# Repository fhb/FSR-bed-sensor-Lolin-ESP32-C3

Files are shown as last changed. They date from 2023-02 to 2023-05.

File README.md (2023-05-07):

# FSR-bed-sensor-Lolin-ESP32-C3
This project includes everything needed to build a bed occupancy sensor inspired by https://community.home-assistant.io/t/fsr-the-best-bed-occupancy-sensor/365795:
One PCB design for connecting two FSR sensors to an Lolin ESP32-C3 pico (pin compatible to Lolin ESP32-C3 mini) and a case for it. There are also two options to add a temperature sensor using the I2c port on the Lolin ESP32-C3. Everything has been tested and works. Make sure the JST-XH plugs are properly plugged in. 

List of materials:

* 2x JST_XH 2 pins male + female connector
* 1x Wemos Lolin ESP32-C3 pico
* 2x 8er Pinleiste
* 2x 8er Buchsenleiste
* 2x RM063 Potentiometer (V2)
* 2x FSR SF15-600 10kg


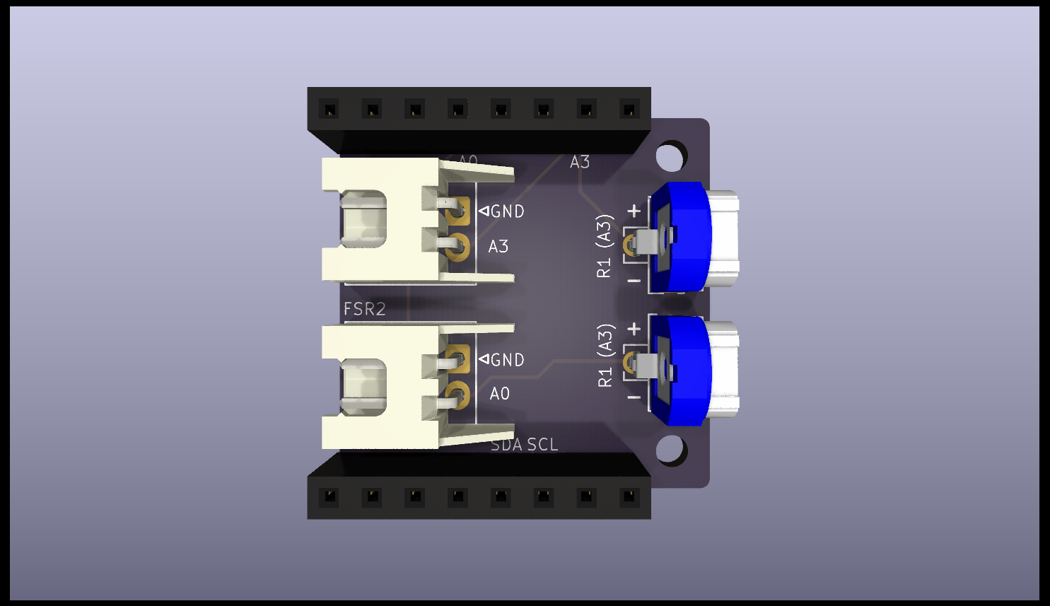
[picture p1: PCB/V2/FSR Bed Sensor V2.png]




Option 1:The Wemos SHT-30 is the easiest option as ready made SH1.0 4Pin cables are available, that's the option I ended up using and designing a case for.
* 1x Wemos SHT-30 (https://www.wemos.cc/en/latest/d1_mini_shield/sht30.html)
* I2C Cable 10cm für LOLIN (WEMOS) SH1.0 4Pins



Option 2: You could also make your own JST-XH to JST-SH1.0 cable and solder a JST-XH connector to a BME280 5V Board. 
* JST-SH1.0 male connector --- 4 wire ---  JST-XH female + male connector 
* BME280 5V Board (I2C)

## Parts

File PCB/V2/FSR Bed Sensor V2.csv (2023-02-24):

Id | Designator | Footprint | Quantity | Designation | Supplier and ref
1 | FSR2 | JST_XH_S2B-XH-A-1_1x02_P2.50mm_Horizontal | 1 | JST_XH_S2B-XH-A-1_1x02_P2.50mm_Horizontal
2 | R1 (A3),R1 (A3) | Potentiometer_Runtron_RM-063_Horizontal | 2 | Potentiometer_Runtron_RM-063_Horizontal
3 | FSR1 | JST_XH_S2B-XH-A-1_1x02_P2.50mm_Horizontal | 1 | ST_XH_S2B-XH-A-1_1x02_P2.50mm_Horizontal
4 | Wemos LOLIN C3 Pico | WEMOS_Lolin_ESP32-C3_Pico | 1 | ESP32-C3

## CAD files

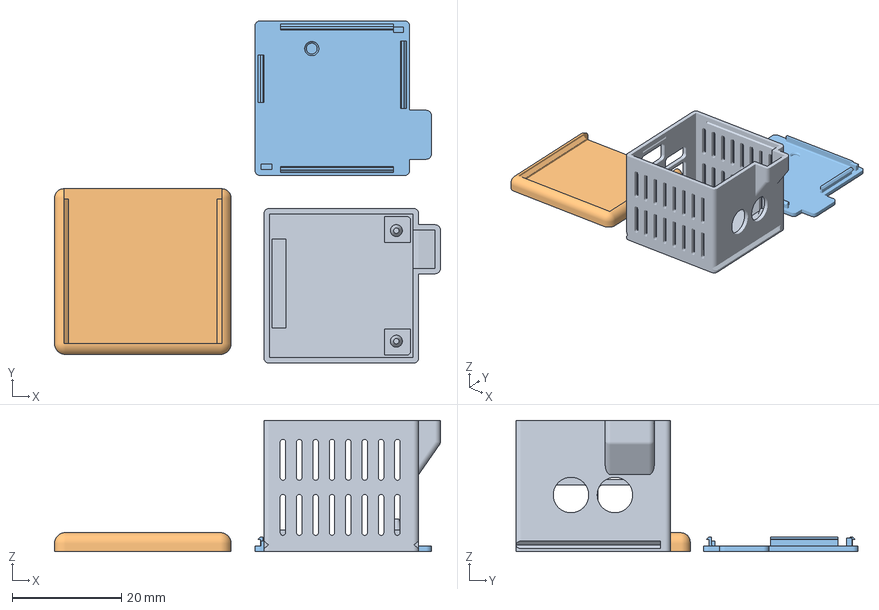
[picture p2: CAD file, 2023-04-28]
Case/FSR Bed Sensor.3mf
70.8 x 62.8 x 24.1 mm
FSR Bed Sensor_Body
FSR Bed Sensor_Mount
FSR Bed Sensor_Lid

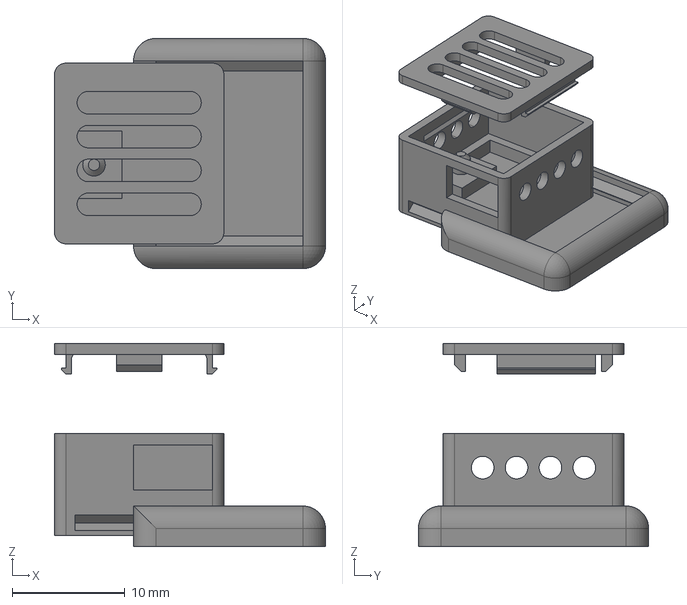
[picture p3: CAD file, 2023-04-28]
Case/Step files/Temp Sensor Case.step
24.0 x 20.4 x 18.0 mm
Lid
Folder 03

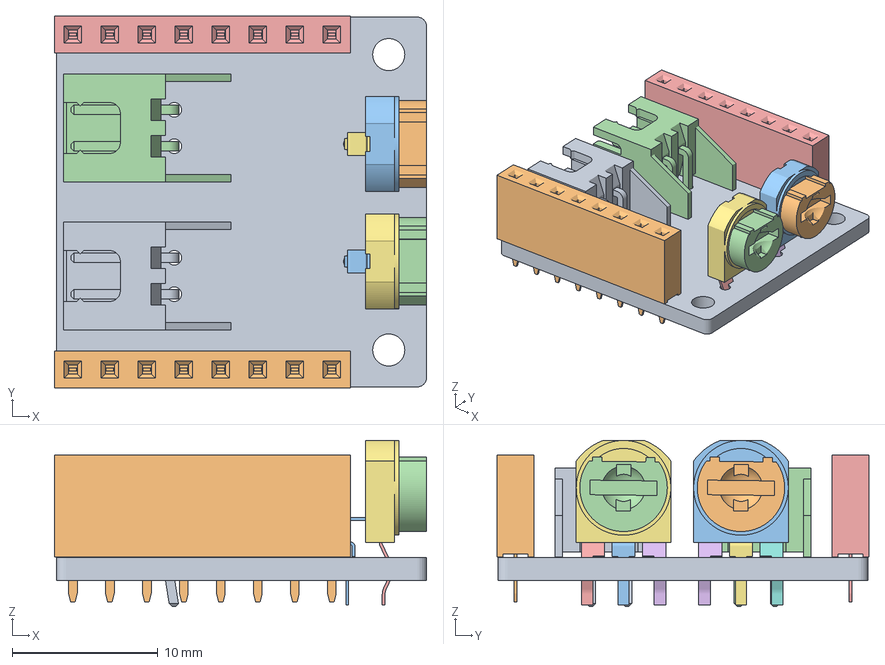
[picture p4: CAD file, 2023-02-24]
PCB/V2/case/FSR Bed Sensor Copy_FSR Bed Sensor V2.step.3mf
25.6 x 25.5 x 11.4 mm
Imported_01
Imported_02
Imported_10
Imported_14
Imported_03
Imported_08
Imported_06
Imported_07
Imported_04
Imported_09
Imported_11
Imported_05
Imported_13
Imported_12
Imported_15

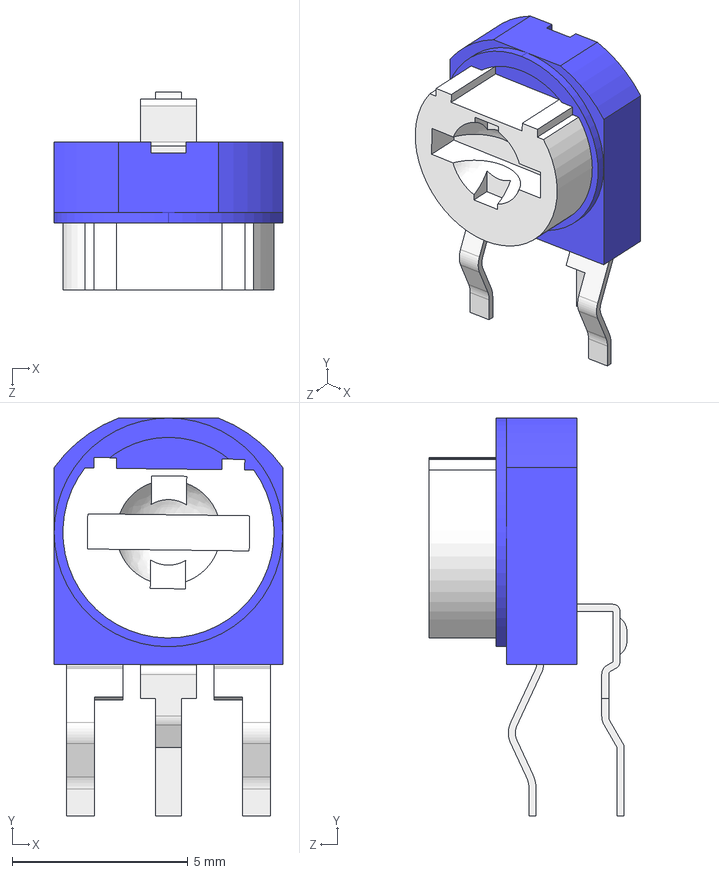
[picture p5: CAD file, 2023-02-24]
PCB/V2/custom 3d models/RM-063.STEP
6.50 x 11.3 x 5.63 mm
User Library-RM-063_d1
User Library-RM-063_d2
User Library-RM-063_d3l
User Library-RM-063_d3r
User Library-RM-063_d3c

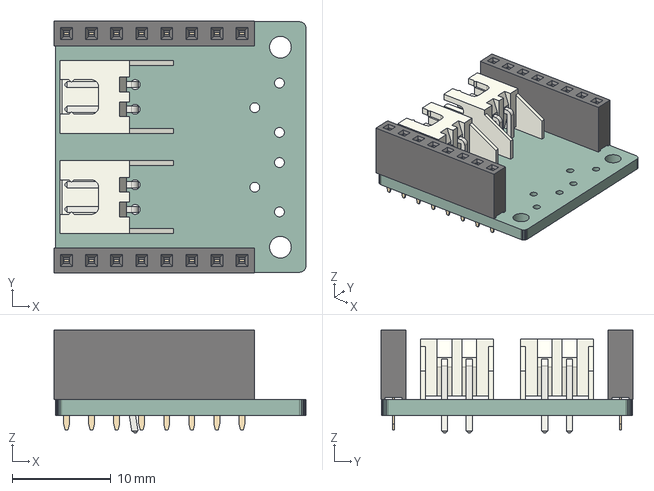
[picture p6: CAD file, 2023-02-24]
PCB/V2/FSR Bed Sensor V2.step
25.5 x 25.5 x 10.4 mm
PCB

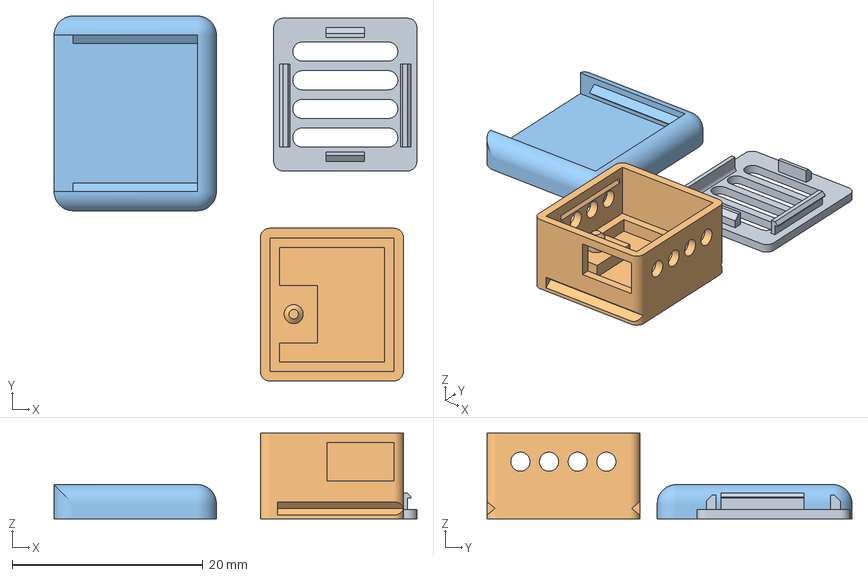
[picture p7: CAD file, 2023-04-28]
Case/Temp Sensor.3mf
38.0 x 38.2 x 9.00 mm
Temp Sensor Case_Lid
Temp Sensor Case_Body
Temp Sensor Case_Mount

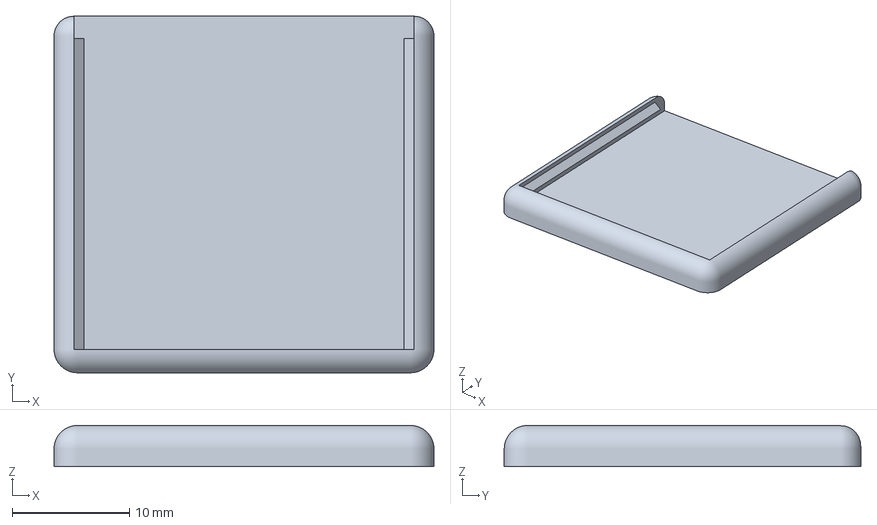
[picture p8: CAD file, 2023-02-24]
PCB/V2/case/FSR Bed Sensor Copy_Holding.3mf
32.4 x 30.4 x 3.50 mm

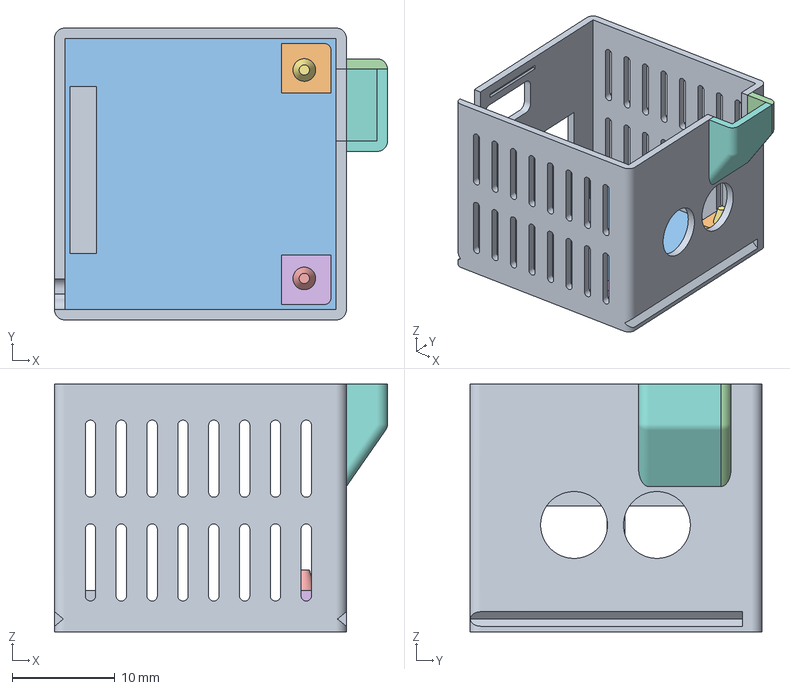
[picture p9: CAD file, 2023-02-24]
PCB/V2/case/FSR Bed Sensor Copy_Body.3mf
32.4 x 28.4 x 24.1 mm
Floor**1
Floor**2
Floor*
Floor**3

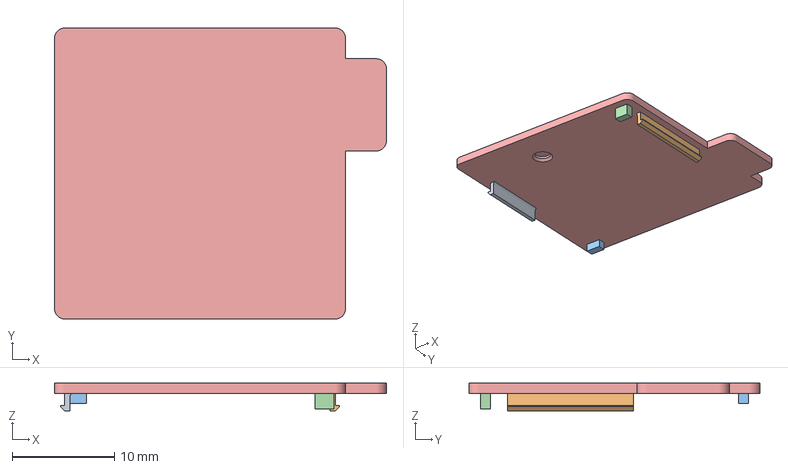
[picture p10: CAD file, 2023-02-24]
PCB/V2/case/FSR Bed Sensor Copy_Lid.3mf
32.4 x 28.4 x 2.70 mm
Lid*2
Lid*2_(1)
Lid*3
Lid*4
Main_Lid*

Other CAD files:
PCB/V2/case/stl/FSR Bed Sensor Copy_Body.stl
PCB/V2/case/stl/FSR Bed Sensor Copy_Holding.stl
PCB/V2/case/stl/FSR Bed Sensor Copy_Lid.stl

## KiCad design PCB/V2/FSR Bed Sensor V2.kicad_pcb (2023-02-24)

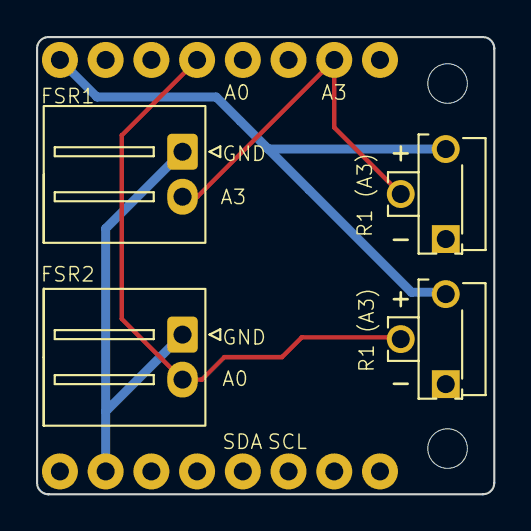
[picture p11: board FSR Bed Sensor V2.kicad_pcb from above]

Board: 2 copper layers, 25.4 x 25.4 mm, 5 parts (0 on the bottom side), 4 nets.

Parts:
FSR1: ST_XH_S2B-XH-A-1_1x02_P2.50mm_Horizontal; JST_XH_S2B-XH-A-1_1x02_P2.50mm_Horizontal
FSR2: JST_XH_S2B-XH-A-1_1x02_P2.50mm_Horizontal
R1 (A3), R1 (A3)#2: Potentiometer_Runtron_RM-063_Horizontal
Wemos LOLIN C3 Pico: ESP32-C3; WEMOS_Lolin_ESP32-C3_Pico

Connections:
3.3V: R1 (A3).1, R1 (A3)#2.1, Wemos LOLIN C3 Pico.8
A0: FSR2.2, R1 (A3).2, Wemos LOLIN C3 Pico.5
A3: FSR1.2, R1 (A3)#2.2, Wemos LOLIN C3 Pico.2
GND: FSR1.1, FSR2.1, Wemos LOLIN C3 Pico.10

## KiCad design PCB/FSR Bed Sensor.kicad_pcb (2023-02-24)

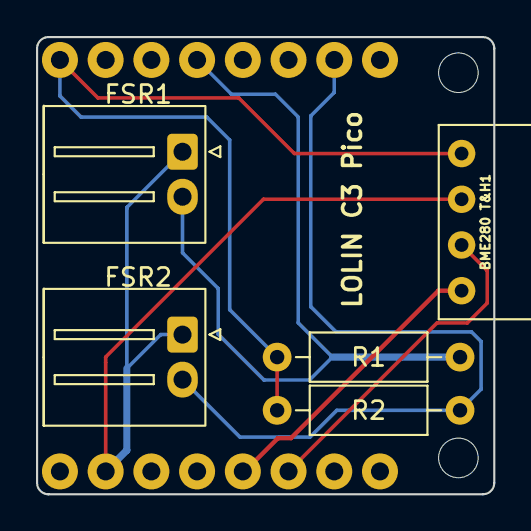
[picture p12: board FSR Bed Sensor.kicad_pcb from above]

Board: 2 copper layers, 25.4 x 25.4 mm, 6 parts (0 on the bottom side), 6 nets.

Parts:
BME280 T&H1: BME280 5V
FSR1: ST_XH_S2B-XH-A-1_1x02_P2.50mm_Horizontal; JST_XH_S2B-XH-A-1_1x02_P2.50mm_Horizontal
FSR2: JST_XH_S2B-XH-A-1_1x02_P2.50mm_Horizontal
LOLIN C3 Pico: ESP32-C3; WEMOS_Lolin_ESP32-C3_Pico
R1, R2: 128kOhm; R_Axial_DIN0207_L6.3mm_D2.5mm_P10.16mm_Horizontal

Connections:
3.3V: BME280 T&H1.1, LOLIN C3 Pico.8, R1.1, R2.1
A0: FSR1.2, LOLIN C3 Pico.5, R1.2
A3: FSR2.2, LOLIN C3 Pico.2, R2.2
GND: BME280 T&H1.2, FSR1.1, FSR2.1, LOLIN C3 Pico.10
SCL: BME280 T&H1.3, LOLIN C3 Pico.14
SDA: BME280 T&H1.4, LOLIN C3 Pico.13

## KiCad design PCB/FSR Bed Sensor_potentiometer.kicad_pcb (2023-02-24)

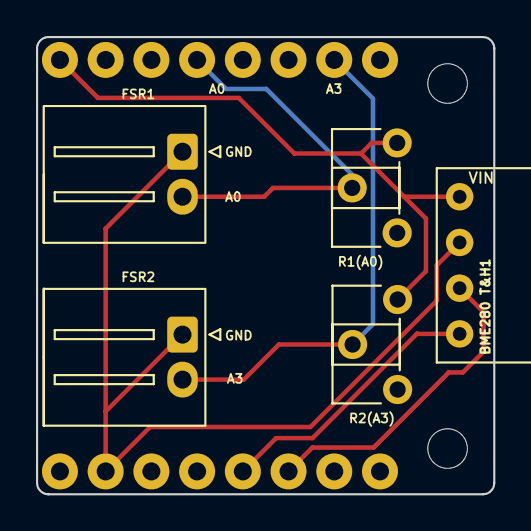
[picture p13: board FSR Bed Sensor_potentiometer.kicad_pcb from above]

Board: 2 copper layers, 25.4 x 25.4 mm, 6 parts (0 on the bottom side), 6 nets.

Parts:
BME280 T&H1: BME280 5V
FSR1: ST_XH_S2B-XH-A-1_1x02_P2.50mm_Horizontal; JST_XH_S2B-XH-A-1_1x02_P2.50mm_Horizontal
FSR2: JST_XH_S2B-XH-A-1_1x02_P2.50mm_Horizontal
R1(A0), R2(A3): Potentiometer_ACP_CA6-H2,5_Horizontal
Wemos LOLIN C3 Pico: ESP32-C3; WEMOS_Lolin_ESP32-C3_Pico

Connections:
3.3V: BME280 T&H1.1, R1(A0).3, R2(A3).3, Wemos LOLIN C3 Pico.8
A0: FSR1.2, R1(A0).2, Wemos LOLIN C3 Pico.5
A3: FSR2.2, R2(A3).2, Wemos LOLIN C3 Pico.2
GND: BME280 T&H1.2, FSR1.1, FSR2.1, Wemos LOLIN C3 Pico.10
SCL: BME280 T&H1.3, Wemos LOLIN C3 Pico.14
SDA: BME280 T&H1.4, Wemos LOLIN C3 Pico.13

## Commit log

2023-01-21 Add files via upload
    corrected the edge cut and added M2 mounting holes at the corners
    [FSR Bed Sensor.kicad_pcb]
2023-01-21 Add files via upload
    cleanup
    [FSR Bed Sensor.kicad_pcb]
2023-02-17 Add files via upload
    switched to CA6-H2,5 potentiometers
    [FSR Bed Sensor Potentiometer.kicad_pcb]
2023-02-17 Add files via upload
    one option with normal resistors and one with CA6 potentiometers
    [FSR Bed Sensor.kicad_pcb, FSR Bed Sensor_potentiometer.kicad_pcb]
2023-02-24 V2 with RM063 and without BME280 on the board
    [FSR Bed Sensor V2.csv, FSR Bed Sensor V2.kicad_pcb, FSR Bed Sensor V2.kicad_sch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]
